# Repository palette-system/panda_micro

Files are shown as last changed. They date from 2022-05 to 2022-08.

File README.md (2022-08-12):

# PandaMicro (🐼micro)

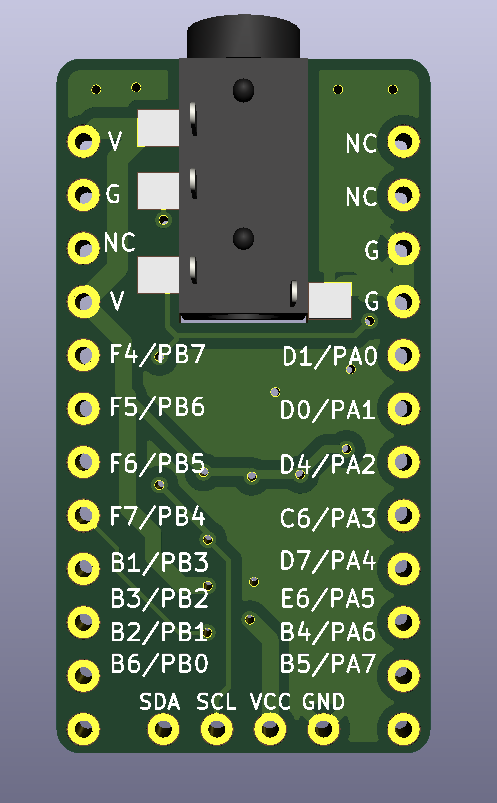
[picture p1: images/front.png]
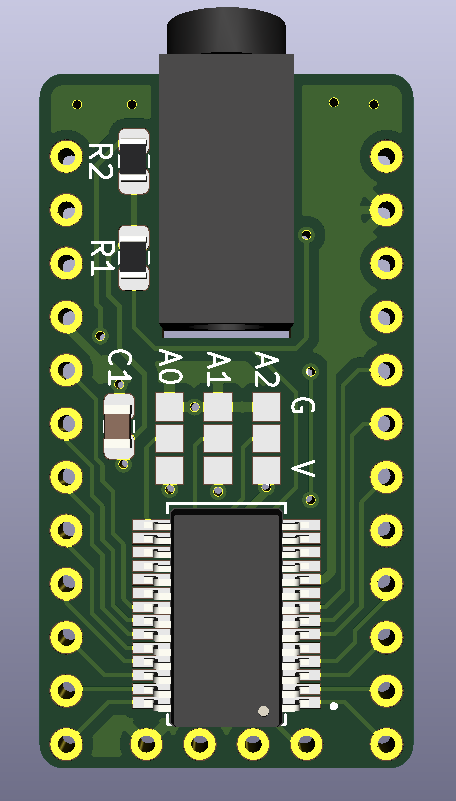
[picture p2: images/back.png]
　
<br><br><br>

## 説明

PandaMicro は MCP23017 を使用した ProMicro サイズのIOエキスパンダモジュールです。  
基板にTRRSジャックが取り付けられているのが特徴で、TRRSを利用してI2C通信を行います。  
ピンの配列は可能な限りProMicroと互換するよう設計していますが一部利用できないピンがあるため注意して下さい。  
<br><br>

## TRRSジャック

<table>
  <tr>
    <td>1</td>
    <td>T</td>
    <td>SCL</td>
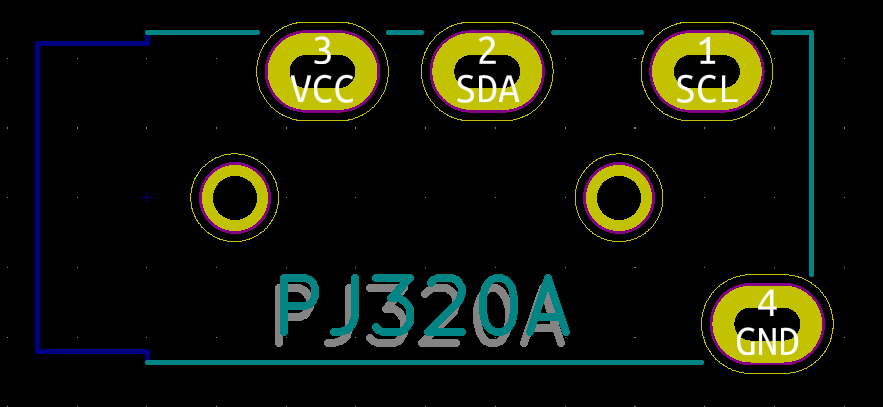
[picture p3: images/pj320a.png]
    <td rowspan="4"></td>
  </tr>
  <tr>
    <td>2</td>
    <td>R</td>
    <td>SDA</td>
  </tr>
  <tr>
    <td>3</td>
    <td>R</td>
    <td>VCC</td>
  </tr>
  <tr>
    <td>4</td>
    <td>S</td>
    <td>GND</td>
  </tr>
</table>
<br><br>

## ProMicroピン互換表

<table>
  <tr>
    <th>No</th>
    <th>ProMicro</th>
    <th>PandaMicro</th>
    <td rowspan="13">　</td>
    <th>No</th>
    <th>ProMicro</th>
    <th>PandaMicro</th>
  </tr>
  <tr>
    <td>1</td>
    <td>D3</td>
    <td>NC</td>
    <td>24</td>
    <td>RAW</td>
    <td>VCC</td>
  </tr>
  <tr>
    <td>2</td>
    <td>D2</td>
    <td>NC</td>
    <td>23</td>
    <td>GND</td>
    <td>GND</td>
  </tr>
  <tr>
    <td>3</td>
    <td>GND</td>
    <td>GND</td>
    <td>22</td>
    <td>RESET</td>
    <td>NC</td>
  </tr>
  <tr>
    <td>4</td>
    <td>GND</td>
    <td>GND</td>
    <td>21</td>
    <td>VCC</td>
    <td>VCC</td>
  </tr>
  <tr>
    <td>5</td>
    <td>D1</td>
    <td>GA0</td>
    <td>20</td>
    <td>F4</td>
    <td>GB7</td>
  </tr>
  <tr>
    <td>6</td>
    <td>D0</td>
    <td>GA1</td>
    <td>19</td>
    <td>F5</td>
    <td>GB6</td>
  </tr>
  <tr>
    <td>7</td>
    <td>D4</td>
    <td>GA2</td>
    <td>18</td>
    <td>F6</td>
    <td>GB5</td>
  </tr>
  <tr>
    <td>8</td>
    <td>C6</td>
    <td>GA3</td>
    <td>17</td>
    <td>F7</td>
    <td>GB4</td>
  </tr>
  <tr>
    <td>9</td>
    <td>D7</td>
    <td>GA4</td>
    <td>16</td>
    <td>B1</td>
    <td>GB3</td>
  </tr>
  <tr>
    <td>10</td>
    <td>E6</td>
    <td>GA5</td>
    <td>15</td>
    <td>F3</td>
    <td>GB2</td>
  </tr>
  <tr>
    <td>11</td>
    <td>B4</td>
    <td>GA6</td>
    <td>14</td>
    <td>B2</td>
    <td>GB1</td>
  </tr>
  <tr>
    <td>12</td>
    <td>B5</td>
    <td>GA7</td>
    <td>13</td>
    <td>B6</td>
    <td>GB0</td>
  </tr>
</table>
<br><br>

## アドレスジャンパーピンの設定

I2C上に複数のpanda_microを接続できるので、どのpanda_microが何番目のpanda_microか判断するために必ずアドレスの設定が必要になります。<br>
アドレスの設定は画像部分のジャンパーピンをはんだ付けして行って下さい。<br><br>
※ 1つしか接続しない場合でもアドレス設定をしないと使用できません。<br><br>

<table><tr><td>
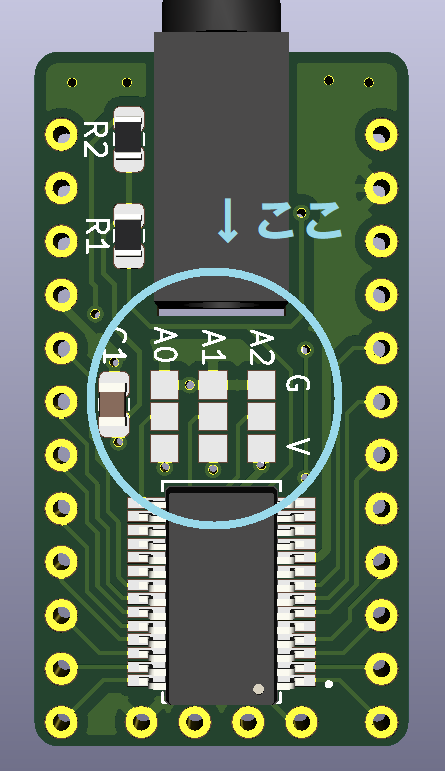
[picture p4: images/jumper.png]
　
</td><td>
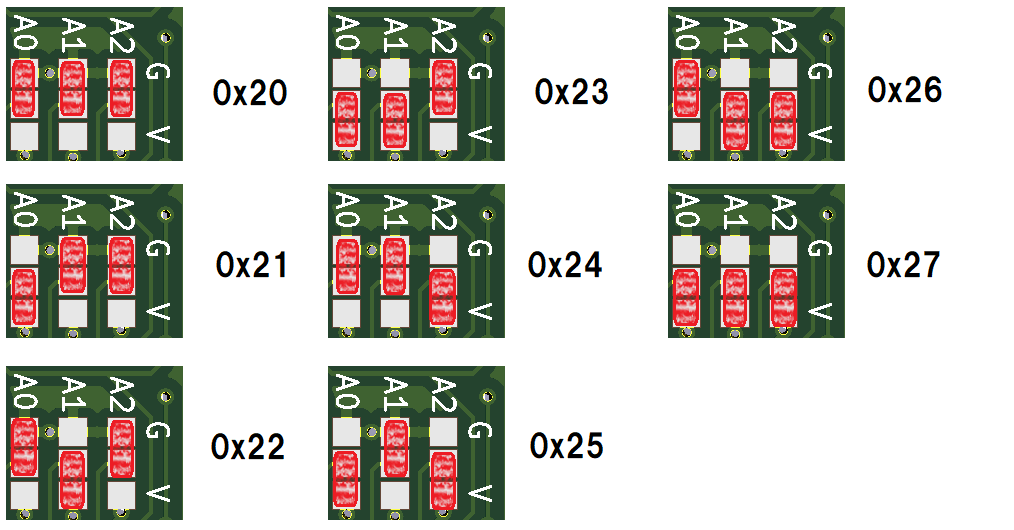
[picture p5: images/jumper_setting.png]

</td></tr></table>
<br><br>

## 対応キーボード

使用したいキーボードの基板データが公開されていればProMicro部分の、画像で言う青い部分でキーの入力を取得しているキーボードは対応しています(Duplex-Matrixは非対応)、オレンジ色の部分でキー入力をしているキーボードは非対応になります(LEDのデータや、左右の通信で使用している分には問題ない)。<br>
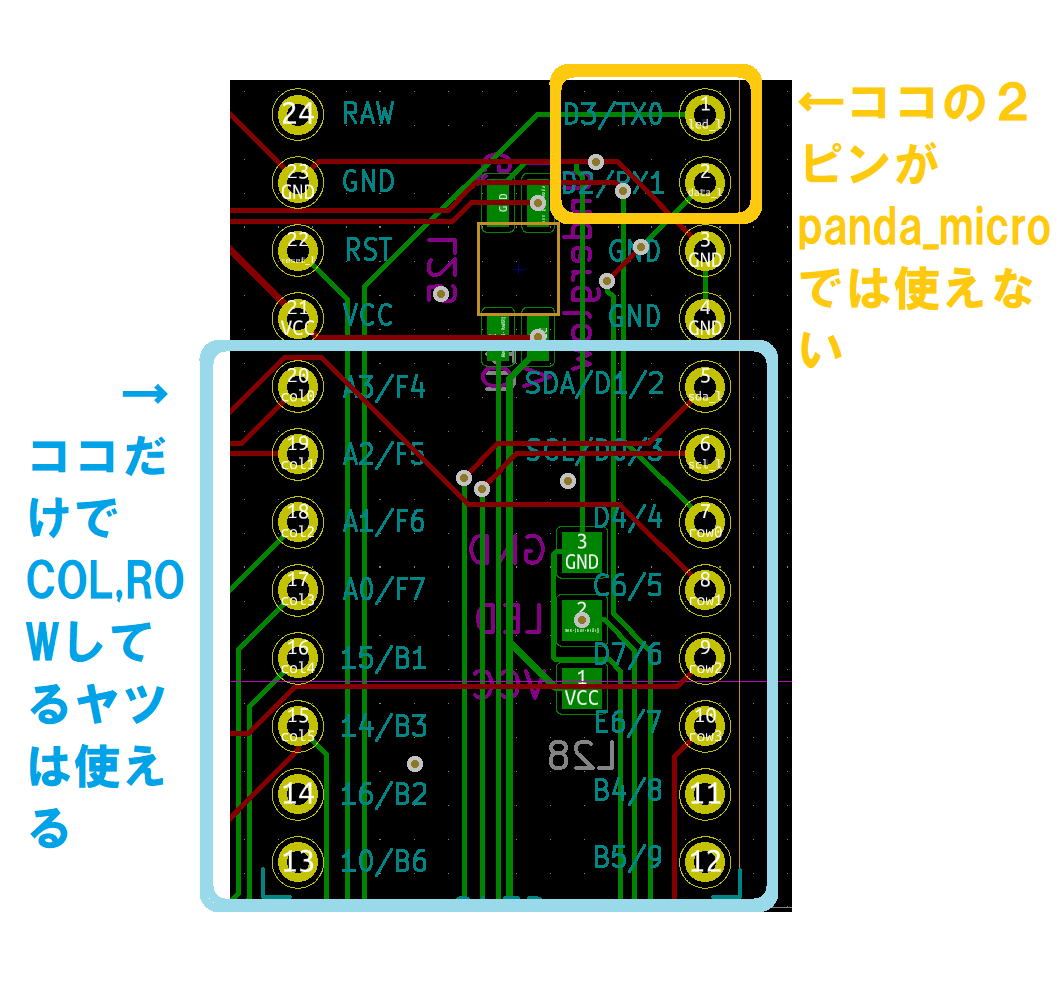
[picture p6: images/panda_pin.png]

<br><br>

■ 使用できる<br>
・スイッチに直繋ぎ(IOピン→スイッチ→GND)<br>
・通常Matrix<br>
・コンスル―<br>
<br>

■ 使用できない<br>
・Duplex-Matrix<br>
・OLED<br>
・トラックボール<br>
・ロータリーエンコーダー<br>
・RGB-LED<br>

## 使用パーツ

<table>
  <tr>
    <th>部品名</th>
    <td>表記</td>
    <td>容量 / 型番</td>
  </tr>
  <tr>
    <th>TRRSジャック</th>
    <td>　</td>
    <td>PJ320D</td>
  </tr>
  <tr>
    <th>IOエキスパンダ</th>
    <td>U1</td>
    <td>MCP23017-E/SS</td>
  </tr>
  <tr>
    <th>コンデンサ</th>
    <td>C1</td>
    <td>0.1μF（サイズ：2012）</td>
  </tr>
  <tr>
    <th>I2Cプルアップ抵抗</th>
    <td>R1、R2</td>
    <td>2.2kΩ（サイズ：2012）</td>
  </tr>
</table>
<br><br>

## 詳細情報

電圧：　1.8V　～　5.5V  
信号：　I2C　（～1.7MHz）
サイズ：　width 17.78mm　×　height 33.02
<br><br>

## 動かない時に確認するポイント

・ジャンパーピンでアドレス設定は必須です。このページの上の方にアドレス設定の説明があるので必ずアドレス設定をして下さい。<br><br>
・TRRSは４極の物のみ対応しています。ケーブルのピンが４極かチェックして下さい。<br><br>
・キーボードに接続した時のpanda_microの表、裏が逆になっていない事を確認して下さい。(キーボードにピンの名前が書いてあると思うので必ずpanda_microに書いてあるピンと合うように接続して下さい)<br><br>
・ケーブルの長さが1mを超えるものだとI2Cのプルアップが足りなくなる場合があるので、他のキーボードで使えていたケーブルだったとしても何本か別のケーブルを試してみて下さい。ケーブルが短い方が繋がりやすいです。<br><br>
・キーボードに付いているLEDやOLEDに電流を持って行かれてIOエキスパンダが電流不足で動かない事があります。panda_microのVCC（Vと書いてあるピン）の所のコンスル―ピンを抜くなどしてキーボードとVCCが繋がらないようにしてみて下さい。<br><br>

## 写真

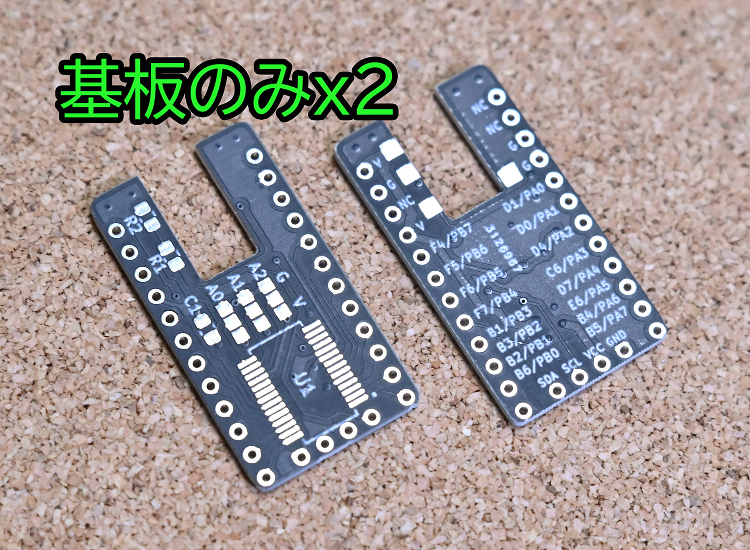
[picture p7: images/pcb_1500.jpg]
<br><br>
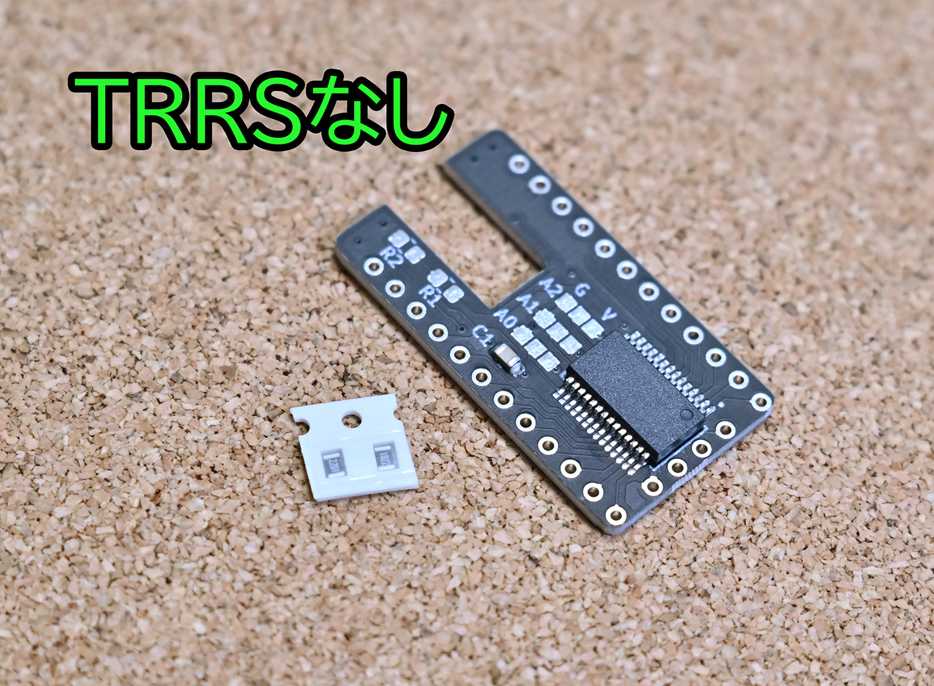
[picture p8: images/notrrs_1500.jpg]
<br><br>
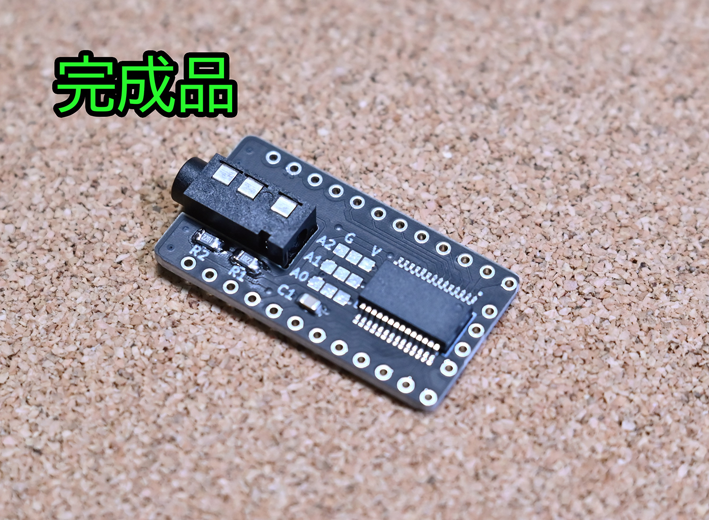
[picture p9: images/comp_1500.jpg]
<br><br>

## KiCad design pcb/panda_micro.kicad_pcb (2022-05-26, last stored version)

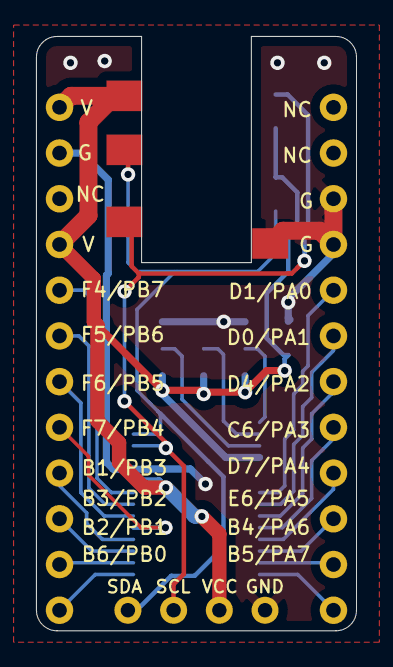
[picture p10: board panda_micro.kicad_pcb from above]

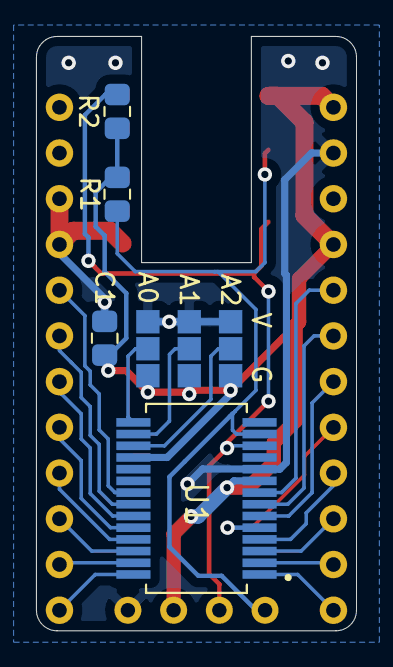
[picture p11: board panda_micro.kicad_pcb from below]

Board: 2 copper layers, 17.8 x 33.0 mm, 6 parts (4 on the bottom side), 20 nets.

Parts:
C1: 1kΩ; R_0805_2012Metric1.2
J1: MJ-4PP-9; MJ-4PP-9_1side
R1, R2: 1kΩ; R_0805_2012Metric1.2
U1: ProMicro; ProMicro_v3
U1#2: SOP65P780X200-28N

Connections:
GND: C1.2, J1.A, U1.3, U1.4, U1.23, U1#2.10
KEY1: U1.5, U1#2.21
KEY2: U1.6, U1#2.22
KEY3: U1.7, U1#2.23
KEY4: U1.8, U1#2.24
KEY5: U1.9, U1#2.25
KEY6: U1.10, U1#2.26
KEY7: U1.11, U1#2.27
KEY8: U1.12, U1#2.28
KEY9: U1.13, U1#2.1
KEY10: U1.14, U1#2.2
KEY11: U1.15, U1#2.3
KEY12: U1.16, U1#2.4
KEY13: U1.17, U1#2.5
KEY14: U1.18, U1#2.6
KEY15: U1.19, U1#2.7
KEY16: U1.20, U1#2.8
SCL: J1.D, R2.2, U1#2.12
SDA: J1.C, R1.2, U1#2.13
VCC: C1.1, J1.B, R1.1, R2.1, U1.21, U1.24, U1#2.9, U1#2.18
